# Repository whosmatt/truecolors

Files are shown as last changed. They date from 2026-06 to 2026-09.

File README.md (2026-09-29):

> [!CAUTION]
> This is not a manual! This repository serves as documentation only, use at your own risk.

# truecolors

This project captures a lot of embedded approaches I have picked up over the years and serves as my main ESP-IDF reference template for new projects that involve an embedded web UI w/ provisioning and OTA. 

Wide color gamut RGB Laser Mood Light  

I designed this light after growing fascinated with wide color gamut (110% BT.2020) rgb laser projectors. The colors are more vibrant and saturated than anything else. Even the best OLED screens look orange in comparison to the deep red produced by the almost monochromatic lasers.  
I got my hands on a Nichia NUMB12 Laser module, a very common module used in low to mid-tier RGB laser projectors.  
Unfortunately, the module is challenging to drive:
- Common cathode rules out most buck drivers which rely on a cathode shunt
- Forward voltage is very different between the green and red/blue channels
- Laser diodes are much more sensitive to overcurrent than LEDs
- The common cathode has a lower rating than the combined maximum currents, so staggered PWM is required to stay within the ratings

Beyond color gamut, this project also focuses on advanced audio reactive effects. Frustrated with RMS multiband effects, I trained a model to predict the presence and offset of beats in live audio, along with tagging drum hits.  
This allows effects to be completely locked into the tempo of a track rather than responding to volume changes. [truecolors-ml repo](https://github.com/whosmatt/truecolors-ml)

## Safety warning

The laser module used is a class 4 laser, with the output wavelength fully in the visible range. This means that the light has maximum eye damage potential and requires a robust safety protocol to be used safely. Use rated laser safety glasses and a shuttered room when testing without diffusers.

### Diffuser safety

I extensively tested the PLEXIGLAS® LED, Clear 0M200 SC diffuser material to ensure that it doesn't degrade under the intense laser light. Other diffuser materials **did** degrade and even slowly deform under the heat. High transmission is a must to minimize local heating, and the diffuser particles need to be the right size to ensure even diffusion across all three channels. Cheap diffusers may have a insufficient particle size, leading to a partially undiffused red beam passing straight through. Don't assume anything, test everything!

The diffuser design **must** include redundancy to ensure that the detachment/failure of a single diffuser does not compromise eye safety.

All fasteners relevant to eye safety must be secured with thread locker. Consider an additional hardware interlock.

## Hardware design

### PCB

A 4-Layer PCB was designed using Kicad 10. 4 layers were chosed to simplify USB 2.0 impedance and reduce laser driver EMI. Hierarchical design was used to keep the project organized, with Kicad's multichannel feature duplicating the laser driver layout. 

### MCU

An ESP32-S3 was chosen as the main controller for this project. It has plenty of power and the USB2.0 capability simplifies the design.  

ESP-IDF was used as the firmware framework, utilizing the rich scheduling and real-time capabilities of FreeRTOS.  
While most of my other projects rely on PlatformIO for toolchain management, I chose to use the official Espressif path for this to have more direct control over the build process.

### Power supply

USB C PD is used to power the design, with active negotiation to 20V/3A (bootstrapped by hardware and controlled by firmware).

### Laser driver

This design uses a customized constant off-time buck driver using the LM3409 switching converter IC. The design is common for all three channels and current is tuned by a multiturn potentiometer.  
COFT ensures known ripple amplitude, allowing the design to use minimal capacitance while staying safely within the laser's ratings.

Staggered PWM using the ESP32's MCPWM peripheral ensures that no two channels are on at the same time. An optional stretch parameters allows the channels to grow into the unused off time up to 100% combined duty with any color. This allows far higher brightness than with traditional staggered PWM.  
No gap was configured since the common cathode constraint is a thermal one, not an electrical one. 

### Temperature management

A heatpipe based server CPU cooler is used in conjunction with a Honeywell PTM7950 phase change thermal pad to keep the laser module cool.

A fine-adjustable 4-pin PWM server fan allows silent cooling with fine temperature control. This is important because the red laser diode array has a derating both above and below 45°C. The fan is PID controlled via the NTC thermistor located on the laser module.  
The tach signal is fed back to the MCU for fault monitoring. 

### Audio

A MSM261DGT003 PDM MEMS microphone is included for audio reactive effects. Connected to the ESP32's I2S peripheral in PDM mode.

A short recording was analyzed for coil whine cancellation: A single comb filter at the MCPWM frequency as well as a ~48db/oct 4kHz lowpass provided good results and leaves plenty of signal for audio reactive effects.

The first design was quite noisy, these mitigations have been tested and are already in the files:
- Lower noise inductors
  - C22396364 is footprint compatible and advertised as "ultra low buzz noise"
  - Small impact, because MLCC noise is dominant
- No output caps
  - With no output caps noise is reduced to a minimum
    Noise is still significantly audible at 240, 480 Hz. 120 Hz recommended
  - Requires carefully trimming to peak current via scope instead of average current
  - degraded EMI

The following hasn't been tested but is recommended:
- Low noise input caps
  - Murata ZRB: Drop in replacement with ~15dB reduction
  - Next board revision should allow for KRM series with ~25dB reduction

## Software design

### Audio

Core 1 is reserved for audio (including inference) and effect rendering.  

<details>
<summary>Audio pipeline diagram</summary>

```mermaid
flowchart TD
    MIC["PDM mic<br/>I2S RX, 48 kHz"] --> BLK["512-sample block<br/>93.75 blocks/s"]

    subgraph CORE1A["audio task: core 1, prio 5"]
        BLK --> FE["fe_block (frontend v2)<br/>DC block → 4 kHz hi-cut<br/>→ band split → multiband AGC"]
        BLK --> MEL["melflux_block<br/>1024 Hann (previous + current block)<br/>→ FFT → 16 mel bands 150 Hz - 4 kHz<br/>→ log10 → positive flux"]
        FE --> FEOUT["fe_out_t: 12 floats<br/>level, bands[3], rms, flux[3],<br/>fund_rms, mid_flux, treble_flux, spl_db"]
        FEOUT & MEL --> X["x: 28 floats"]

        X --> PA["stage A projection<br/>28 → 12, float"]
        PA --> RA["ring A: 272 blocks × 12"]
        RA --> WA["window: 528 floats<br/>16 fine + 16 mid + 12 coarse<br/>+2 block lookahead"]
        WA --> NNA[["TFLM + esp-nn, int8<br/>stage A 528→128→64 → beat<br/>76k MAC"]]
        NNA --> FB["stage A beat of the<br/>previous block: a[n-3]"]

        X & FB --> PB["stage B projection<br/>29 → 12, float"]
        PB --> RB["ring B: 272 blocks × 12"]
        RB --> WB["window: 528 floats"]
        WB --> NNB[["TFLM + esp-nn, int8<br/>stage B 528→64→32<br/>36k MAC"]]
        NNB --> HEADS["beat, beat_offset, hit[4], music"]

        HEADS -- beat --> TRACK["beattrack<br/>phase accumulator, latches each observation<br/>unlocked: fires on activation ≥ 0.5"]
        HEADS -- beat --> ABUF["tempo ringbuffer: 750 blocks / 8 s"]
        HEADS -- music --> GATE["musicgate<br/>median over ~2 s @ 0.7<br/>+ 3 s hold-off"]
    end

    subgraph CORE1B["estimator task: core 1, prio 3"]
        ABUF --> EST["tempo_estimate every 0.5 s, after ~14 s settle<br/>unbiased autocorr → harmonic sum, fractional lag →<br/>subharmonic → joint period+phase"]
        EST --> HOLD["hold: keep the held grid unless the candidate<br/>refines it, beats its contrast over the last 4 s<br/>by 0.02, or the held contrast drops below 0.03"]
    end

    HOLD -- "period, to_next, contrast<br/>(seqlock observation)" --> TRACK

    TRACK --> FEAT["audio_features_t<br/>level · bands[3] · beat · grid<br/>bpm · kicks · spl_db"]
    FEOUT --> FEAT
    GATE -. "currently debug only" .-> TEL

    FEAT --> FX["effects render task<br/>core 1, prio 18, 90 Hz<br/>reads beat, grid, bands"]
    FX --> LASER["laser_set → MCPWM"]

    HEADS -- *all* --> EVT["EVT_BEATGRID, block rate<br/>kick/snare/hihat/met<br/>act · music · off · err<br/>period · phase · bpm"]
    TRACK --> EVT
    FEAT --> TEL["metrics, 1 Hz<br/>audioDb · bpm<br/>nn.{beat,music,cycles,arena}<br/>nn.gate · nn.track · nn.selftest"]

    subgraph CORE0["core: 0"]
        EVT
        TEL
    end
```

</details> 

## Web UI

The Web UI is based on Svelte 5 and vite, and served as a gzipped static bundle. It is baked into the app partition via CMake's `target_add_binary_data`.  
A websocket endpoint is used to sync the UI state with the firmware, and events are propagated to other connected clients, making the UI multi-user capable.

## Development Environment & Build Instructions

The official Espressif dev container is used and should automatically be detected in VS Code. Build via the status bar, the command palette or just `idf.py build`.  
Build contains all stages, including web.  

### Tests

Critical components have unit tests via Unity, run them via `cd test/host && idf.py build && ./build/truecolors_host_tests.elf`.  

### Flashing & Debugging

Access to USB devices from the dev container is a little tricky. 
Refer to the [Espressif documentation](https://docs.espressif.com/projects/vscode-esp-idf-extension/en/latest/additionalfeatures/docker-container.html) for (partially out of date) instructions.  
WSL2 distros commonly don't have USB drivers loaded.  
Run `echo -e "cp210x\nch341\ncdc_acm" | sudo tee /etc/modules-load.d/esp.conf` inside your WSL2 distro and restart WSL2. The dev container is set up to get access to all ttyACM and ttyUSB class devices. Always make sure WSL2 is running before starting the dev container, as wsl is responsible for loading the kernel modules.  

Flashing via OTA: `curl -X POST --data-binary @build/truecolors.bin http://truecolors.local/api/ota`

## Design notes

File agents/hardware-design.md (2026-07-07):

# truecolors — Hardware Design Reference

Reference for firmware development. Describes the board, power tree, and every
ESP32 connection. Authoritative source is [`pcb/truecolors_driver.kicad_sch`](../pcb/truecolors_driver.kicad_sch);
this document reflects that schematic as built. See
[`timer-strategy.md`](timer-strategy.md) for the peripheral/timing plan.

## Project summary

110% BT.2020 mood light driven by a **Numb12 RGB laser array** (common cathode).
Each color is powered by its own **LM3409** P-channel buck LED driver (one
hierarchical sheet each: `driverR`, `driverG`, `driverB`, all instances of
`numb12_driver.kicad_sch`). The ESP32-S3 dims each color by PWM-ing the driver's
`EN`/PWM input.

**Hard constraint:** the laser array has a **common cathode and is NOT rated for
all diodes on simultaneously.** Firmware must guarantee the three colors are
driven **sequentially / non-overlapping** at all times — including during
brightness updates. This is enforced by the MCPWM scheme in
[`timer-strategy.md`](timer-strategy.md).

## MCU

**ESP32-S3-WROOM-1 (N8R8)** — 8 MB flash, 8 MB **octal** PSRAM.

- Octal PSRAM consumes **GPIO35, 36, 37** (datasheet Table 3-1 footnote b) — do
  not use. GPIO33/34 are not bonded out.
- Strapping pins (avoid for I/O that matters at boot): **GPIO0, 3, 45, 46**.
- Not 5 V tolerant — abs max ~3.6 V on any GPIO. Every pull-up that touches the
  ESP32 goes to **3.3 V**, never to 5 V or VBUS/20 V.
- Native USB-Serial-JTAG on GPIO19/20 is used for the USB port, so pad-JTAG
  (GPIO39/40 = MTCK/MTDO) is free for reuse as laser enables.

## Power tree

```
USB-C ──(PD sink: CH224A)──► +20V ──(AP63205 buck)──► +5V ──(AMS1117 LDO)──► +3.3V
         CFG1 = 120k → 20V        U1                    U4
```

| Rail  | Source | Notes |
|---|---|---|
| +20 V | USB-C VBUS, negotiated by **CH224A (U2)** PD sink | Feeds all three LM3409 laser drivers (VIN) and the +5 V buck |
| +5 V  | **AP63205WU-7 (U1)** buck, L4 = 4.7 µH | Fan supply + LDO input |
| +3.3 V| **AMS1117-3.3 (U4)** LDO | ESP32, pull-ups, sensor logic |

The 20 V rail establishes from the **CFG1 = 120 kΩ → GND** strap on the CH224A at
power-on, independent of firmware (single-resistor mode also auto-enables I²C on
CFG2/CFG3). Lasers are held off by their EN pulldowns until firmware drives them.

## Pin map (final, verified against schematic)

| Net | GPIO | Module pin | Peripheral (firmware) | Electrical notes |
|-----|---|---|---|---|
| EN_R | GPIO40 | 33 | MCPWM op (laser R) | active-high; 10k pulldown; → driverR PWM |
| EN_G | GPIO39 | 32 | MCPWM op (laser G) | active-high; 10k pulldown; → driverG PWM |
| EN_B | GPIO38 | 31 | MCPWM op (laser B) | active-high; 10k pulldown; → driverB PWM |
| VIN_ADC | GPIO4 | 4 | ADC1_CH3 | 20 V rail sense via divider (below) |
| FAN_PWM | GPIO6 | 6 | LEDC, 25 kHz | **inverted output** (low-side BSS138) |
| FAN_TACH | GPIO7 | 7 | PCNT | 10k (R25) pull-up to 3.3 V |
| CH224A_SDA | GPIO8 | 12 | I²C master SDA | 2.2k (R22) pull-up to 3.3 V |
| CH224A_SCL | GPIO9 | 17 | I²C master SCL | 2.2k (R23) pull-up to 3.3 V |
| IO0 / BOOT | GPIO0 | 27 | boot strap / button | SW1 + 10k (R16) pull-up to 3.3 V |
| TX / RX | GPIO43/44 | 37/36 | UART0 console | CN1 programming header |
| USB D-/D+ | GPIO19/20 | 13/14 | USB-Serial-JTAG | USB-C DM/DP |
| MIC_CLK | GPIO12 | 20 | I²S PDM CLK | no series R (short trace); → MIC1 CLK |
| MIC_DATA | GPIO13 | 21 | I²S PDM DATA RX | no series R (short trace); ← MIC1 DATA |
| NTC_ADC | GPIO10 | 18 | ADC1_CH9 | laser module NTC sense via divider (below) |
| LED_DATA | GPIO11 | 19 | RMT TX | WS2812B-B data |

## Subsystems

### Laser drivers (R / G / B) — LM3409

- Each color = one LM3409MY P-channel buck on its own sheet, `VIN = +20 V`,
  output to the laser, common cathode to GND.
- The `EN`/PWM input is **directly 3.3 V compatible and active-high** (high =
  laser current on). Driven by MCPWM — see [`timer-strategy.md`](timer-strategy.md).
- **Boot safety:** each EN net has a **10 kΩ pulldown** so the laser is OFF while
  the GPIO is Hi-Z (reset / flashing / before firmware init).
- The LM3409 dims by gating EN; each rising edge restarts the converter, which
  needs settle time. This sets a **dimming floor** (shortest useful on-time ≈
  converter settle time, `MIN_ON_US` = 8 µs) and argues for a **low** PWM/cycle
  frequency — see the timing doc for the rationale.
- **Low-power shutdown (measured, datasheet §8.4.1):** a sustained EN low lets
  the VCC bias rail (regulated ~6.2 V below VIN, held by a 1 µF cap) decay past
  UVLO into 110 µA shutdown; the next enable pays a soft restart visible as a
  fade-in. Short PWM-dimming lows keep the support circuitry alive (§8.3.6);
  tens-of-ms dark states do not. EN is a single Schmitt input (rising ≤1.74 V,
  falling ≥0.5 V) — there is **no intermediate "standby" drive level**, so the
  fix is temporal: firmware floors dark channels at MIN_ON pulses for effects
  that strobe from black (`keepalive` flag).

### Fan — 4-wire (5-pin) PC fan, run on 5 V via low-side PWM

Connector **CN2 = Molex 47053-1000** fan header. The fan is a 12 V 4-wire PC fan
run on **+5 V** (validated: smooth control).

- **CN2 pin 1** = GND, **pin 2** = +5 V, **pin 3** = TACH, **pin 4** = PWM control.
- The fan's PWM input does **not** meet Intel logic levels — measured idle ≈
  **1.58 V** on 5 V supply (≈3.3 V on 12 V).
- **Measured transfer (2026-07-07): the fan never fully stops.** Holding the
  PWM line at GND leaves a ~84 rpm min-speed floor (vendor behavior); response
  is dead until a **19% duty knee**, then linear `rpm ≈ 1875·duty − 250` to
  1621 rpm at 100%, no hysteresis. Firmware remaps the PID output onto
  `[knee, 1]` accordingly.
- **Control = low-side switch via BSS138 (Q4):**
  - Gate ← FAN_PWM (GPIO6), with **R26 pull-up to 3.3 V** (boot disabled).
  - Source → GND.
  - Drain → CN2 pin 4.
  - The fan's own internal pull-up provides the idle-HIGH (no external pull-up).
- **Inverted logic:** GPIO6 HIGH → FET on → fan PWM line LOW → fan OFF.
  Firmware sets `output_invert` so the LEDC duty register maps directly to fan
  speed (see timing doc).
- **Boot behavior:** while GPIO6 is Hi-Z, R26 pulls the gate HIGH → FET on →
  fan PWM line held LOW → **fan disabled at boot** until firmware takes over.
- **TACH (CN2 pin 3):** open-collector, 2 pulses/rev (confirmed), pulled up to
  3.3 V (R25 10k). Valid because the fan supply is constant 5 V (not chopped).
  Read with PCNT, both edges over a 1 s window (15 rpm resolution).
- The fan's 5th pin (presence-detect to GND) is **not used**.

### 20 V rail measurement — ADC

- Divider: **R21 = 68 kΩ (top, from +20 V)** / **R20 = 10 kΩ (bottom)**, with
  **C40 = 100 nF** across the bottom for filtering + ADC sample charge reservoir.
- Scale factor: `V_rail = V_adc × (68 + 10) / 10 = V_adc × 7.8`.
  20 V → 2.56 V at the ADC; clips near ~24 V (≈21% headroom).
- Read on **ADC1_CH3 (GPIO4)** — ADC1 only, since ADC2 is unusable while Wi-Fi is
  active. Use 12 dB attenuation, eFuse calibration, oversample.
- This is the only **measured** rail voltage; the CH224A reports negotiated gear
  and current capability but not actual VBUS, so this divider is not redundant.

### Microphone — MSM261DGT003 PDM MEMS (MIC1)

- **MSM261DGT003**: omnidirectional, top-ported, 4×2×1.1 mm LGA, VDD = 3.3 V
  (1.6–3.6 V range; 670 µA typical in standard mode).
- **MIC_CLK (GPIO12)** → CLK; **MIC_DATA (GPIO13)** ← DATA. No series resistors
  (traces < 5 mm; ESD diodes also omitted for this enclosed prototype).
- **L/R (pin 6) = GND** → left-channel / Mic(Low): mic asserts DATA on CLK falling
  edge, host latches on rising edge. Matches ESP-IDF I²S PDM-RX default.
- **VDD decoupling**: 100 nF + 10 µF ceramic (C41, C42) immediately at pin 1.
- **Clock**: standard performance mode requires 1.1–4.0 MHz. Use ~3.072 MHz
  (48 kHz × 64); drive from ESP32-S3 I²S peripheral in PDM-RX mode.
- Mode is set by clock frequency alone — sleep ≤ 50 kHz, low-power 150–900 kHz,
  standard 1.1–4.0 MHz. No control register.
- **Top-ported package**: acoustic port faces away from PCB

### Status LED — WS2812B-B (LED1)

- Single WS2812B-B RGB LED; VDD = **+5 V** (from the +5 V rail), GND.
- **LED_DATA (GPIO11, module pin 19)** → data in. Driven by **RMT TX** peripheral
  (one of 4 available channels; none previously allocated).
- Firmware: ESP-IDF `led_strip` driver (RMT backend). For static color, write once
  at init; LED holds state until power-cycled. Reset pulse ≥ 50 µs handled
  automatically by the driver.

### Laser module NTC — temperature monitoring

- **10 kΩ NTC, B = 3950**, mounted on the Numb12 laser module (nominal operating
  temperature 45 °C).
- Read on **ADC1_CH9 (GPIO10, module pin 18)** — ADC1 only (ADC2 unusable with
  Wi-Fi active). GPIO10 is the last free ADC1 pin; sits adjacent to MIC_CLK/DATA.
- **Divider**: 10 kΩ pullup to 3.3 V (near ESP32) / NTC lower leg to GND.
  Midpoint ≈ 1.0 V at 45 °C, well within 12 dB attenuation range.
- **Filter cap**: 100 nF across NTC at the board-edge connector (NTC cable entry),
  not at the ESP32. Filters cable-induced noise at the source. No second cap at the
  ESP32 end — without series impedance between them the two caps would simply be in
  parallel, losing the entry-point filtering benefit.
- Measurement range: −14 °C to +114 °C; resolution ~0.03 °C/LSB at 45 °C.
- ADC config: same as VIN_ADC — 12 dB attenuation, eFuse calibration, oversample.
- Temperature conversion (B-value equation):
  ```c
  float r_ntc  = 10000.0f * v_adc / (3.3f - v_adc);
  float temp_k = 3950.0f / (logf(r_ntc / 10000.0f) + 3950.0f / 298.15f);
  float temp_c = temp_k - 273.15f;
  ```
- **Safety interlock**: add NTC in-range check to the laser-enable gate alongside
  PD handshake and VIN ADC checks (see safety invariant 2).

### USB-C PD sink — CH224A (I²C-only)

- Negotiates **20 V** from the USB-C source. CFG1 = 120 kΩ → GND selects 20 V and
  enables I²C; PG pin is **not connected** (monitoring is via I²C polling only).
- I²C: 400 kHz, **7-bit address 0x22 or 0x23** (confirm on hardware), **single-
  byte read/write only** (no auto-increment).
- Registers used by firmware:
  - **0x09** (RO, status): bit3 = PD handshake good; bits 0/1/2 = BC/QC2/QC3;
    bit5 = EPR exist; bit6 = AVS exist.
  - **0x50** (RO, current): max available current in the negotiated gear, unit
    **50 mA/count** (valid only after handshake).
  - **0x0A** (WO, voltage): request gear — `0`=5 V, `1`=9 V, `2`=12 V, `3`=15 V,
    `4`=20 V, `5`=28 V. Not required (CFG1 strap already selects 20 V), but
    available to re-assert/override.
- **No hardware fault interlock** (PG dropped): firmware must gate laser enable on
  I²C checks (PD good + adequate current) and the ADC reading, and re-poll
  periodically.

## Safety invariants for firmware

1. **Never drive two laser EN lines high at once** (common cathode) — guaranteed
   by the MCPWM single-timer scheme with Σ(on-time) + guards ≤ period and atomic
   updates. See [`timer-strategy.md`](timer-strategy.md).
2. **Lasers off until power is confirmed:** before enabling MCPWM laser outputs,
   confirm CH224A PD handshake (0x09 bit3) + sufficient current (0x50) + ADC rail
   in range + NTC temperature in range. The 10k EN pulldowns hold lasers off until
   then; re-check NTC periodically and disable on over-temperature.
3. **All ESP32-facing pull-ups go to 3.3 V**, never 5 V/20 V (not 5 V tolerant).
4. Supply current budget: compare the CH224A-reported budget (0x50 × 50 mA)
   against the measured draw model `I(V) ≈ 3.68 − 0.106·V` + 0.2 A margin
   (2.4 A @ 12 V, 2.1 A @ 15 V, 1.55 A @ 20 V). A short budget raises the
   undercurrent **warning only** — no brightness limiting; an actual overdraw
   trips the PD supply, and the light recovers to its default-off boot state.

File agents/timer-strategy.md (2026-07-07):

# truecolors — Timer / Peripheral Strategy

Firmware reference for how the ESP32-S3 hardware peripherals generate all timed
signals. Goal: do everything in hardware, no software-bit-banged PWM. Pin/net
details are in [`hardware-design.md`](hardware-design.md).

Peripheral allocation:

| Subsystem | Peripheral | Why |
|---|---|-----|
| RGB lasers | **MCPWM** (1 group, 1 timer, 3 operators) | phase-shifted non-overlapping pulses + atomic synchronous update |
| Fan speed | **LEDC** (1 timer + 1 channel, 25 kHz) | simple high-res PWM, inverted output |
| Fan tach | **PCNT** | hardware pulse counting, zero CPU |
| Rail voltage | **ADC1** (CH3) + calibration | ADC2 unusable with Wi-Fi |
| PD sink status | **I²C master** (polled) | CH224A status/current registers |

---

## 1. Laser PWM — the core scheme

### Concept: phase-shifted PWM with Σduty ≤ 100%

The requirements — *sequential / non-overlapping*, *common cathode never all-on*,
*stretchable slots (R can be 100% if G=B=0)*, *brightness = on-time* — are all one
waveform: **three phase-offset pulses sharing one timer period**, where the sum of
the three pulse widths (plus guard gaps) is ≤ the period.

- Non-overlap ⇒ common-cathode-safe, for free.
- "Stretch" ⇒ free: any single color can take (almost) the whole period when the
  others are 0; the only rule is Σ ≤ period.
- Brightness of a color = its pulse width / period.

### MCPWM mapping

One MCPWM **timer** sets the period; three **operators** share it, each producing
one pulse via its two comparators (set output HIGH at CMPA, LOW at CMPB):

```
period T  ├─────────────────────────────────────────────┤  (repeats)
R         ███████░                                            high 0 → dR
G                 ░░gap░░███████░                             high dR+gap → dR+gap+dG
B                              ░░gap░░██████░                 high ... → ...+dB
                                            ░░gap░░  (wrap)
```

- R: CMPA = 0,                           CMPB = dR
- G: CMPA = dR + gap,                     CMPB = dR + gap + dG
- B: CMPA = dR + 2·gap + dG,              CMPB = dR + 2·gap + dG + dB
- **Invariant:** `dR + dG + dB + 3·gap ≤ T` (three guard gaps: R→G, G→B, B→wrap).

Outputs are **active-high, NOT inverted** (LM3409 EN: high = laser on).

### Frequency choice

- One timer period = one full R→G→B sequence, so **PWM frequency = RGB cycle
  frequency** (the two collapse into a single waveform — do NOT stack a second
  higher-frequency PWM on top; for a buck driver that only adds settling losses).
- **Runtime-adjustable: 120 / 240 / 480 Hz** (settings dropdown → WS
  `set_pwm_hz` → NVS `pwm_hz`), default **120 Hz** — quietest coil whine, still
  above flicker fusion for a static light. Lower frequency = better buck
  behavior, more dimming range, quieter; higher = more motion robustness.
- Frequency changes are glitch-free while running: the period and all six
  comparators shadow-load on the same TEZ (`update_period_on_empty`), and
  `laser_set_pwm_hz()` orders the writes so a TEZ landing mid-update never
  leaves a compare beyond the counter range (growing period → period first,
  shrinking → comparators first).

### Resolution

The MCPWM group clock runs at **5 MHz** (0.2 µs/tick): the period register is
**16-bit** (max 65,535 ticks), and 120 Hz needs 41,666 — a 10 MHz clock cannot
reach below ~153 Hz. At 480 Hz the period is still 10,416 ticks (~13 bits),
far more brightness resolution than needed.

### Wrap-tick reservation (learned the hard way)

The up-counter counts `[0, period−1]`; a compare value equal to the period tick
is accepted by the driver but **never fires** — the clear action is lost and the
channel latches ON at 100% duty, overlapping its neighbors (observed as bright
flashes at crossfade corners with stretch > 25%). The width math therefore
reserves the last tick so every clear compare stays reachable; a width of
period−1 means "fully on" and laser.c drives it as a DC force level instead of
chopping a one-tick notch into EN.

### Guard interval (`gap`)

Settled at **0**. The common-cathode constraint is thermal, not electrical —
these are three independent bucks, not an H-bridge, so there is no
shoot-through path and back-to-back pulses are fine. The gap stays plumbed
through `laser_math.c` should it ever be needed.

### Atomic, glitch-free updates (critical)

Brightness changes must never momentarily push two pulses into overlap. With
MCPWM, **stage all three operators' new CMPA/CMPB and load them synchronously on
the timer zero event (TEZ)** so the three pulses always move as one set and the
`Σ + guards ≤ T` invariant holds every period. Use the MCPWM compare-update-on-
TEZ mechanism; do not update operators one at a time without sync.

### Brightness → on-time pipeline (firmware)

1. Inputs: desired per-color brightness `bR, bG, bB` (0…1, e.g. after gamma).
2. Compute raw widths: `dX = bX × T_available`, where
   `T_available = T − 3·gap`.
3. **Normalize if over budget:** if `dR + dG + dB > T_available`, scale all three
   by `T_available / (dR+dG+dB)` (preserves color ratio) — or clip per policy.
   When the sum is under budget, no scaling: unused time is just idle (all lasers
   off), which is correct.
4. Compute the three (CMPA, CMPB) pairs as above.
5. Stage + sync-load on TEZ.

> Note: normalization couples absolute brightness to the sum. If you want
> "stretch for max brightness" behavior (one color brighter when others are dim),
> that is exactly step 3 with scaling only on overflow — a dim scene leaves the
> bright color at its requested width, a maxed-out white scene shares the period.

### Width floors and the LM3409 keepalive

- A nonzero width below **MIN_ON** (8 µs LM3409 settle floor) snaps up to it.
- **LM3409 low-power shutdown (measured):** a sustained EN low lets the IC's
  VCC bias cap decay below UVLO into 110 µA shutdown; the next enable pays a
  soft restart that shows as a visible fade-in. Normal PWM-dimming lows (≤ one
  period) never trigger it, but tens-of-ms dark states do. Effects that strobe
  from black (discombobulate, audio) set a `keepalive` flag: commanded-dark
  channels then idle at MIN_ON pulses to keep the bias awake. The power switch,
  safety latch, boot gate and brightness-zero still drop to true black.

### Optional power/thermal cap

Σduty ≤ 100% already guarantees at most one laser on at a time (cathode safe). A
separate firmware policy may further cap the **sum of brightnesses** to stay
within the CH224A current budget (0x50) and array thermal limits.

---

## 2. Fan PWM — LEDC, inverted

- **LEDC**, one timer + one channel, **25 kHz** (inaudible; 40 µs period rides
  through the fan's internal commutation so no stutter), on **GPIO6**.
- Hardware is a **low-side BSS138** (gate-driven): GPIO HIGH → FET on → fan PWM
  line LOW → fan OFF. So **set `ledc_channel_config_t.flags.output_invert = 1`**.
  With invert, the **LEDC duty register maps directly to fan speed**.
- **Measured transfer curve (2026-07-07):** the fan never fully stops — ~84 rpm
  floor at 0% duty (vendor min-speed behavior; PWM line verified held low),
  dead until a **19% knee**, then linear `rpm ≈ 1875·duty − 250` up to 1621 rpm
  at 100%, no hysteresis. The PID output is treated as *cooling demand* and
  remapped onto `[FAN_KNEE_DUTY, 1]` so the loop sees a linear plant
  (see `fancontrol.c`).
- Resolution: a few hundred steps is plenty; e.g. 10-bit at 25 kHz.
- **Boot behavior:** before LEDC init, GPIO6 is Hi-Z, R26 pulls the gate HIGH →
  FET on → fan line held LOW → **fan disabled at boot**. Initialize LEDC at any
  point in startup; fan stays off until commanded.

## 3. Fan tach — PCNT

- **PCNT** unit counting edges on **GPIO7** (FAN_TACH, pulled to 3.3 V).
- `pulses_per_rev = 2` (confirmed on hardware). Count **both edges**
  (4 edges/rev) and integrate a full **1 s window** before computing: at a
  100 ms poll a single pulse is worth 300 rpm of quantization, while the
  both-edge 1 s window resolves 15 rpm — needed to see the ~84 rpm idle floor.
- Valid because the fan supply is constant 5 V (not chopped) — tach references a
  stable ground.

## 4. Rail voltage — ADC1

- **ADC1_CH3 / GPIO4**, 12 dB attenuation, eFuse calibration (`adc_cali`).
- `V_rail = V_adc × 7.8` (68k/10k divider; C40 = 100 nF filter).
- Oversample (e.g. average N samples). ADC1 mandatory — ADC2 is blocked while
  Wi-Fi is on. Use as a sanity check on the actual 20 V rail (sag detection),
  complementary to the CH224A's negotiated-gear info.

## 5. PD sink (CH224A) — I²C polling

- **I²C master**, SDA = GPIO8, SCL = GPIO9, 400 kHz, address **0x22/0x23**
  (confirm), **single-byte transactions only**.
- Startup gate sequence before enabling lasers:
  1. (20 V already requested by the CFG1 strap.)
  2. Poll **0x09** until bit3 (PD) = 1 → handshake good.
  3. Read **0x50** → max current = value × 50 mA; compare against the measured
     draw model `I(V) = 3.68 − 0.106·V` + 0.2 A margin (2.4 A @ 12 V …
     1.55 A @ 20 V). A short budget is a **warning only** — no brightness
     limiting; an actual overdraw trips the supply, and the light recovers to
     its default-off boot state.
  4. Confirm ADC rail in range.
  5. Then start MCPWM laser outputs.
- Re-poll 0x09 / 0x50 periodically at runtime. There is **no hardware PG
  interlock** — this poll + the ADC are the only power-fault detection, so on a
  failed check, command all laser widths to 0 (and rely on the EN pulldowns).

---

## Init order (suggested)

1. GPIO defaults / ensure EN pulldowns effective (lasers off).
2. LEDC fan (optional: set a sane speed early to quiet the full-speed boot state).
3. I²C + CH224A startup gate (PD good, current budget, ADC rail check).
4. MCPWM timer + 3 operators, TEZ-synced compare updates, start with all widths 0.
5. Begin the brightness control loop (gamma → widths → normalize → sync-load).

## Resolved on hardware

- CH224A I²C address: firmware probes 0x22 then 0x23 at init.
- Fan `pulses_per_rev` = 2, confirmed; full transfer curve measured (see §2).
- Guard `gap` = 0 — thermal constraint, not electrical.
- Laser cycle frequency: runtime dropdown 120/240/480 Hz, default 120 Hz
  (coil whine); MCPWM group clock 5 MHz to fit 120 Hz in the 16-bit period.
- LM3409 low-power shutdown on sustained EN low → `keepalive` width floor.

## Open items to confirm on hardware

- MIN_ON_US (LM3409 settle floor) — 8 µs assumed, verify on scope.

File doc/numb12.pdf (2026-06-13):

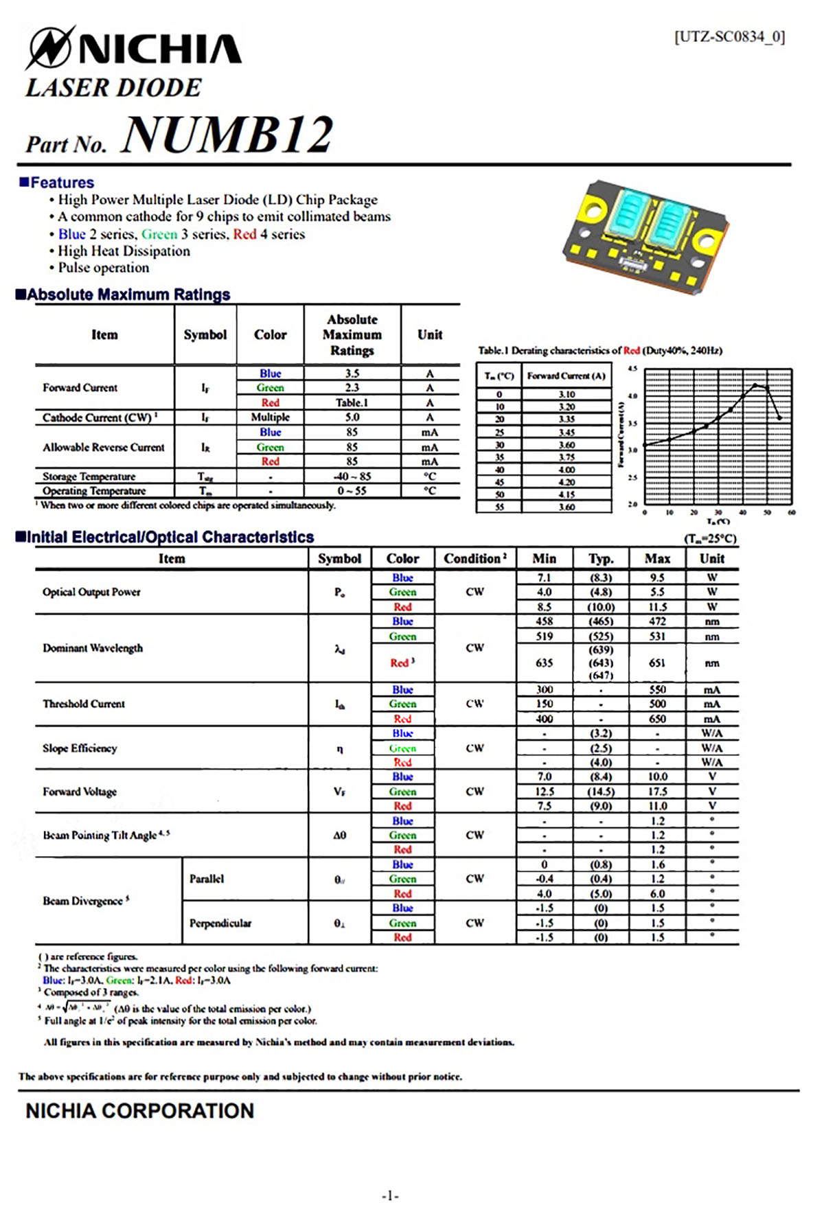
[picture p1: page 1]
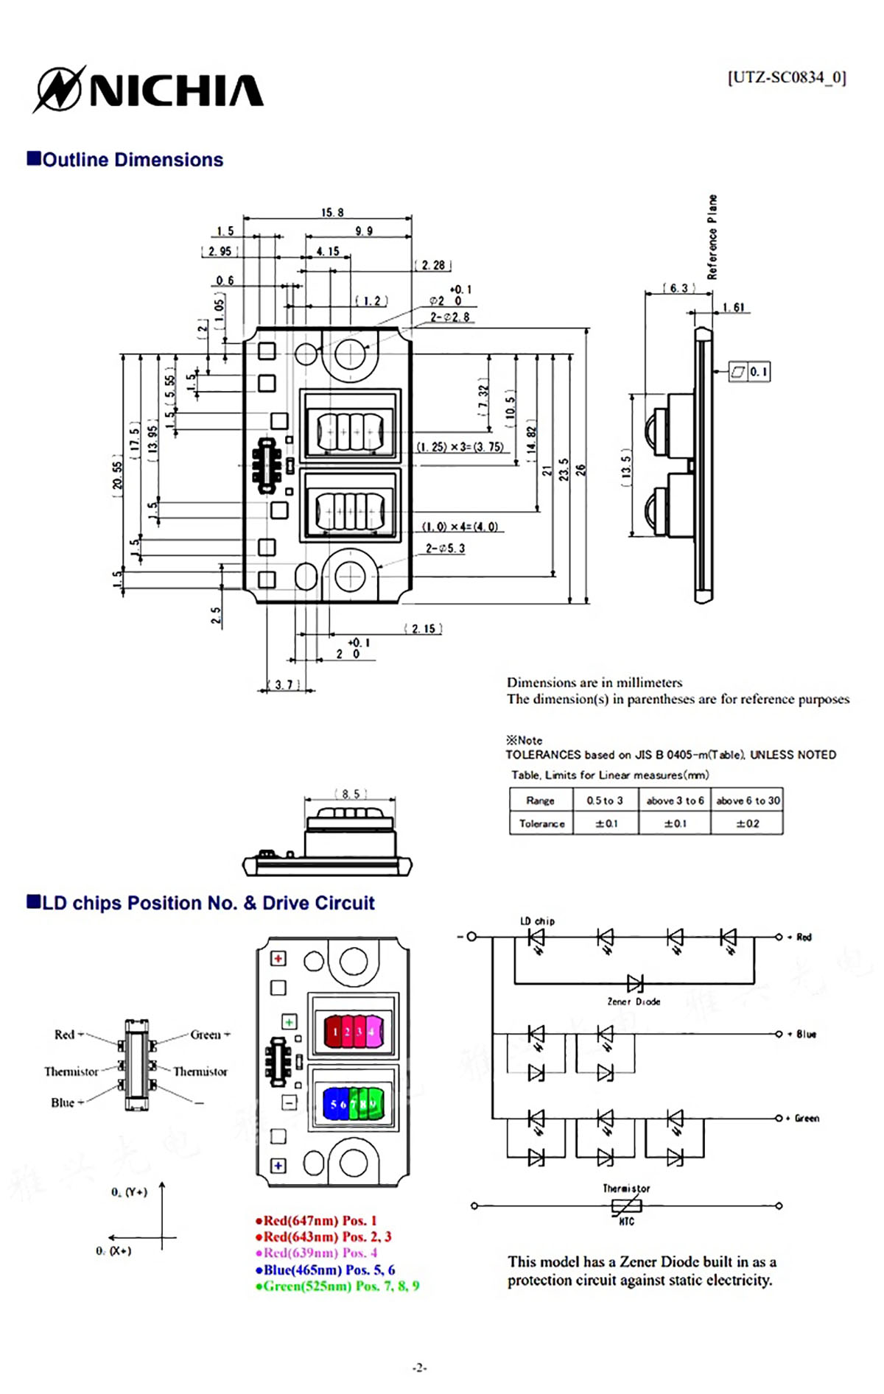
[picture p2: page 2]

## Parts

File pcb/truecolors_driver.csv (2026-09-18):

Reference | Value | Datasheet | Footprint | Qty | DNP | Exclude from BOM | LCSC Part
C1,C7,C17,C27 | 1uF 50V |  | Capacitor_SMD:C_0603_1608Metric | 4 |  |  | C5199872
C2,C3,C34,C36,C37,C38,C39,C42 | 10uF 25V |  | Capacitor_SMD:C_0603_1608Metric | 8 |  |  | C96446
C4,C5,C6,C13,C14,C15,C16,C23,C24,C25,C26,C33 | 4.7uF 35V |  | Capacitor_SMD:C_0603_1608Metric | 12 |  |  | C307467
C8,C18,C28 | 470pF 50V |  | Capacitor_SMD:C_0603_1608Metric | 3 |  |  | C16194503
C9,C10,C11,C12,C19,C20,C21,C22,C29,C30,C31,C32 | 4.7uF 35V |  | Capacitor_SMD:C_0603_1608Metric | 12 | DNP |  | C307467
C35,C40,C41,C43 | 100nF 16V |  | Capacitor_SMD:C_0603_1608Metric | 4 |  |  | C346192
CN1 | 1.0-3PWT | https://www.lcsc.com/datasheet/C2763613.pdf | EasyEDA:CONN-SMD_3P-P1.00_C3029342 | 1 |  |  | C2763613
CN2 | 47053-1000 | https://lcsc.com/product-detail/Others_MOLEX_47053-1000_MOLEX-47053-1000_C240840.html | EasyEDA:CONN-TH_47053-1000 | 1 |  |  | C240840
D1,D2,D3 | SBR8U60P5-13 | https://lcsc.com/product-detail/Diodes-General-Purpose_DIODES_SBR8U60P5-13_SBR8U60P5-13_C154726.html | Library:POWERDI-5_L5.4-W4.0-LS6.5-RD-thermal | 3 |  |  | C154726
L1,L2,L3 | SMPQ1306-220MT |  | easyeda2kicad:IND-SMD_L13.5-W12.8_APH1265T | 3 |  |  | C22396364
L4 | 4.7uH | https://www.lcsc.com/datasheet/C5349668.pdf | EasyEDA:IND-SMD_L4.4-W4.2 | 1 |  |  | C5349668
LED1 | WS2812B-B | https://lcsc.com/product-detail/Light-Emitting-Diodes-LED_5050-RGBIntegrated-Light-4Pin_C114586.html | EasyEDA:LED-SMD_4P-L5.0-W5.0-BL_TC5050RGB | 1 |  |  | C114586
MIC1 | MSM261DGT003 | https://www.lcsc.com/datasheet/C48227730.pdf | EasyEDA:MIC-SMD_6P-L4.0-W2.0_LMD4020T261-OC3 | 1 |  |  | C48227730
Q1,Q2,Q3 | AOD413A(UMW) |  | Library:TO-252-3_L6.6-W6.1-P4.57-LS9.9-BR-CW-thermal | 3 |  |  | C19100585
Q4 | BSS138 | https://www.onsemi.com/pub/Collateral/BSS138-D.PDF | Package_TO_SOT_SMD:SOT-23 | 1 |  |  | C52895
R1,R6,R11 | 50k |  | Resistor_SMD:R_0603_1608Metric | 3 |  |  | C861451
R2,R7,R12 | 6k8 |  | Resistor_SMD:R_0603_1608Metric | 3 |  |  | C2907055
R3,R8,R13 | 3296W-1-254LF | https://lcsc.com/product-detail/Precision-Potentiometer_BOURNS_3296W-1-254LF_250KR_C83691.html | Library:RES-ADJ-TH_3296W-clean | 3 |  |  | C83691
R4,R9,R14 | 14k |  | Resistor_SMD:R_0603_1608Metric | 3 |  |  | C723488
R5,R10,R15 | 75m 675mW |  | Resistor_SMD:R_1206_3216Metric | 3 |  |  | C2904225
R16,R17,R18,R19,R20,R25,R27 | 10k |  | Resistor_SMD:R_0603_1608Metric | 7 |  |  | C2906982
R21 | 68k |  | Resistor_SMD:R_0603_1608Metric | 1 |  |  | C114633
R22,R23 | 2k2 |  | Resistor_SMD:R_0603_1608Metric | 2 |  |  | C2907005
R24,R26 | 120k |  | Resistor_SMD:R_0603_1608Metric | 2 |  |  | C2907095
SW1 | TS-1088-AR02016 | https://lcsc.com/product-detail/Tactile-Switches_XUNPU-TS-1088-AR02016_C720477.html | EasyEDA:SW-SMD_L3.9-W3.0-P4.45 | 1 |  |  | C720477
U1 | AP63205WU-7 | https://www.lcsc.com/datasheet/C2071056.pdf | EasyEDA:TSOT-23-6_L2.9-W1.6-P0.95-LS2.8-BL | 1 |  |  | C2071056
U2 | CH224A |  | easyeda2kicad:ESSOP-10_L4.9-W3.9-P1.0-LS6.0-TL-EP | 1 |  |  | C42459160
U3 | ESP32-S3-WROOM-1(N8R8) |  | easyeda2kicad:WIRELM-SMD_ESP32-S3-WROOM-1 | 1 |  |  | C2913201
U4 | AMS1117-3.3 | https://lcsc.com/product-detail/Low-Dropout-Regulators-LDO_AMS_AMS1117-3-3_AMS1117-3-3_C6186.html | easyeda2kicad:SOT-223-3_L6.5-W3.4-P2.30-LS7.0-BR | 1 |  |  | C6186
U5,U6,U7 | LM3409MY/NOPB |  | Library:HVSSOP-10_L3.0-W3.0-P0.50-LS4.9-BL-EP-thermal | 3 |  |  | C527401
USBC1 | TYPE-C-31-M-12 | https://lcsc.com/product-detail/USB-Type-C_Korean-Hroparts-Elec-TYPE-C-31-M-12_C165948.html | easyeda2kicad:USB-C_SMD-TYPE-C-31-M-12_1 | 1 |  |  | C165948

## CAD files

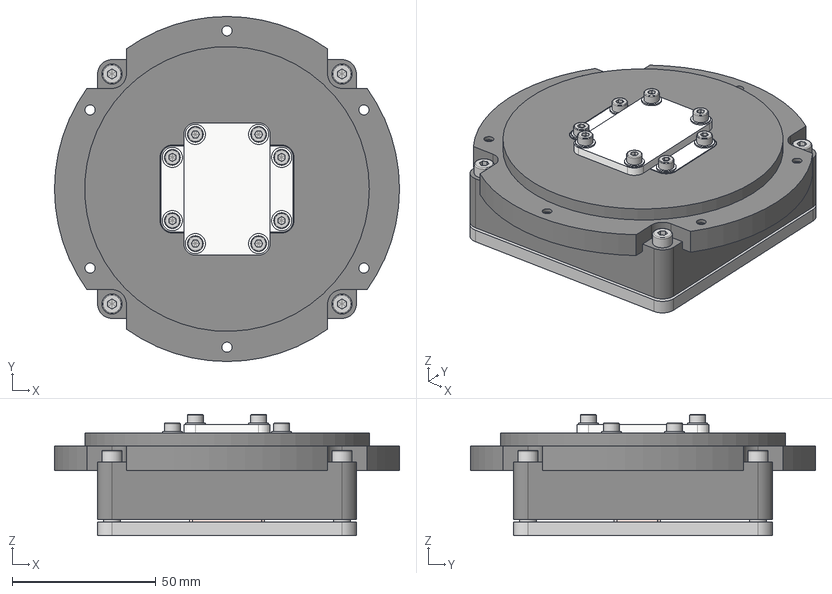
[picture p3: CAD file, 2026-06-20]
mechanical/full assy.step
120.0 x 120.0 x 42.2 mm
NUMB12
Heatsink
Diffusor x 2
DIN 912 - M3 x 0.5 x 8 Steel 4.6 Plain x 8
DIN 433 - 3.7 Steel 100 HV Plain x 8
DIN 912 - M4 x 0.7 x 8 Steel 4.6 Plain x 4

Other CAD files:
mechanical/full assy.f3z

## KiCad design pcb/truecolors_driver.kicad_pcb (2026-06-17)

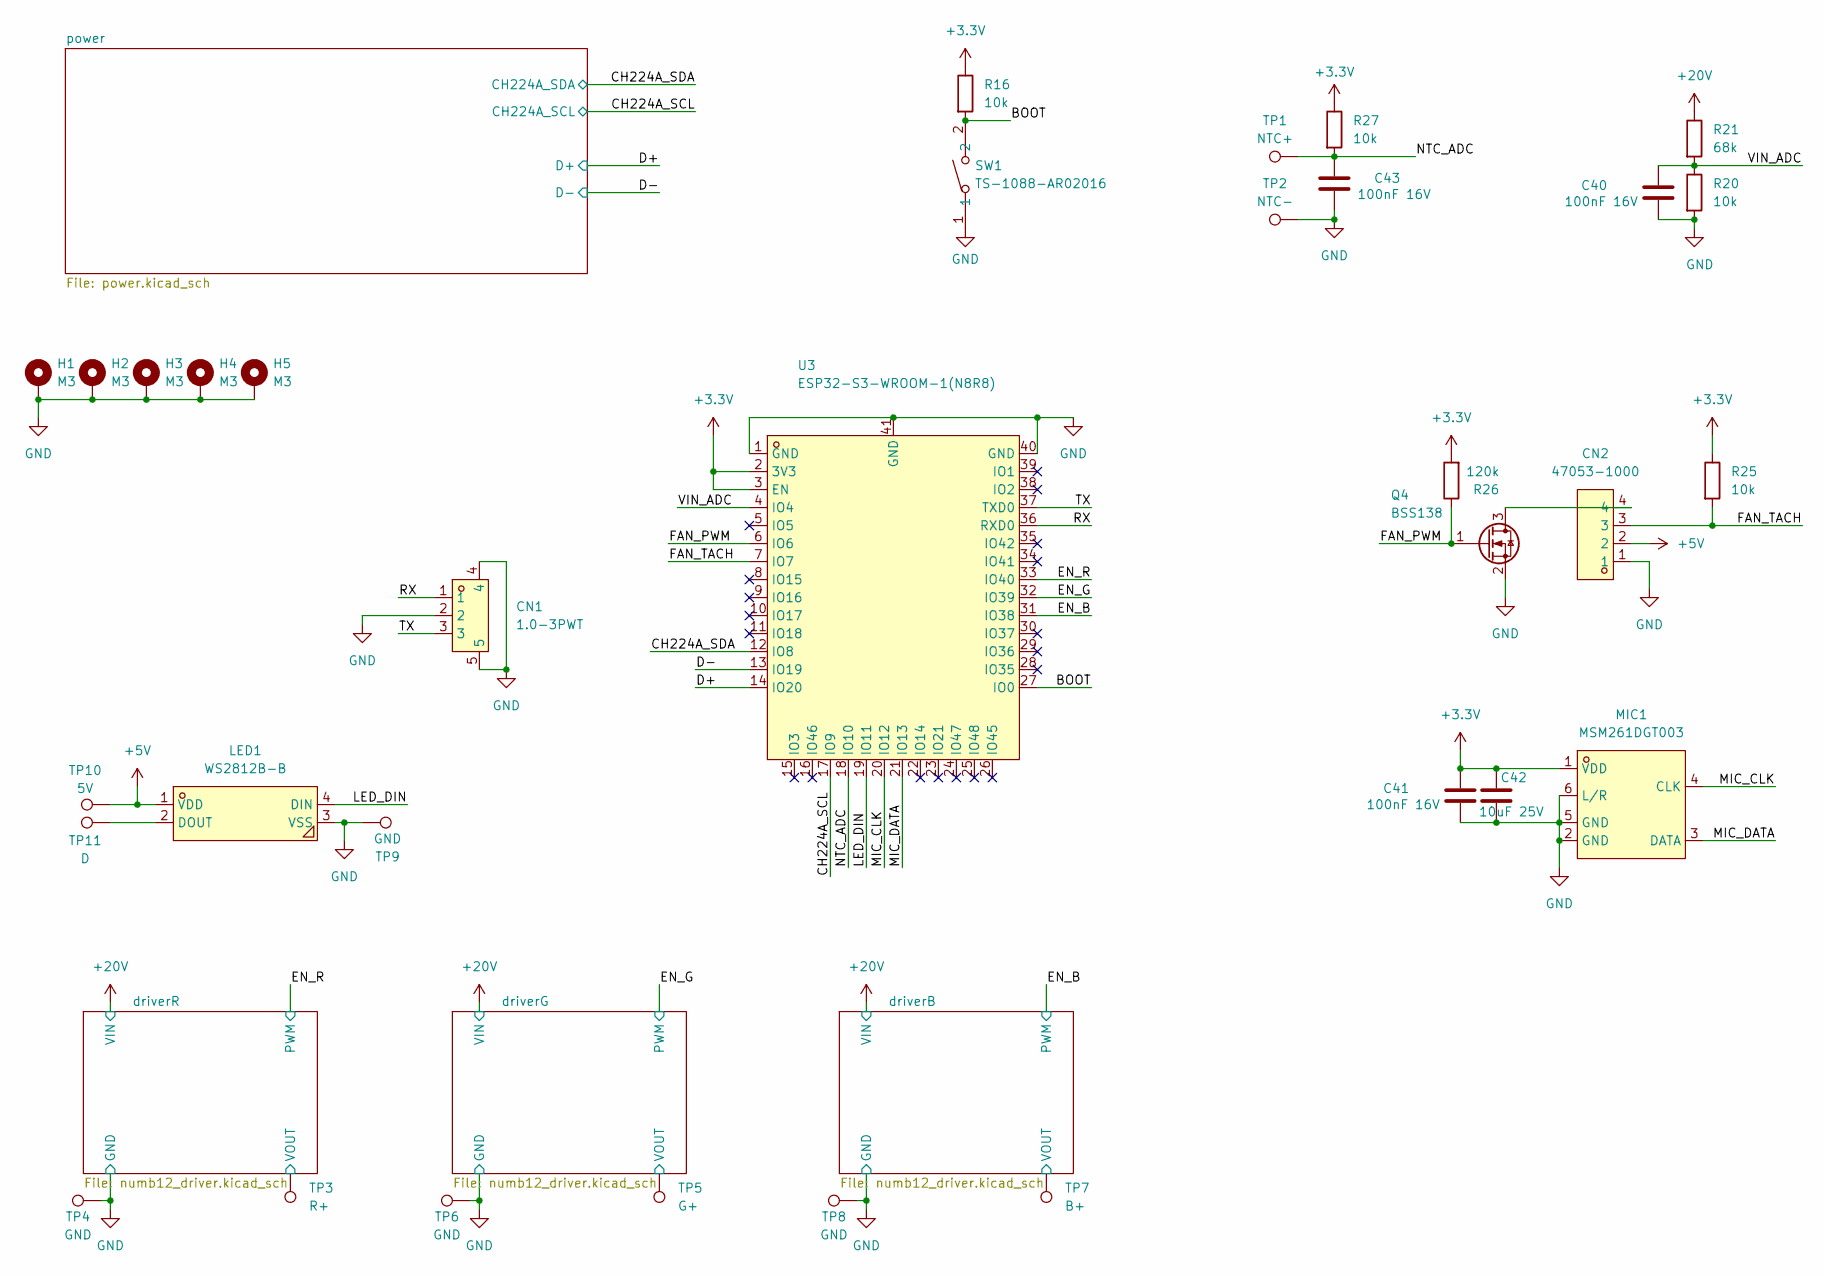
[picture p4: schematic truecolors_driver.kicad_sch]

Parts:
C40, C41, C43: 100nF 16V; C_0603_1608Metric; LCSC Part C346192
C42: 10uF 25V; C_0603_1608Metric; LCSC Part C96446
CN1: 1.0-3PWT; CONN-SMD_3P-P1.00_C3029342; MPN 1.0-3PWT; LCSC Part C2763613
CN2: 47053-1000; CONN-TH_47053-1000; MPN 470531000; LCSC Part C240840
H1, H2, H3, H4, H5: M3; MountingHole_3.2mm_M3_DIN965_Pad
LED1: WS2812B-B; LED-SMD_4P-L5.0-W5.0-BL_TC5050RGB; MPN WS2812B-B/W; LCSC Part C114586
MIC1: MSM261DGT003; MIC-SMD_6P-L4.0-W2.0_LMD4020T261-OC3; MPN MSM261DGT003; LCSC Part C48227730
Q4: BSS138; SOT-23; LCSC Part C52895
R16, R20, R25, R27: 10k; R_0603_1608Metric; LCSC Part C2906982
R21: 68k; R_0603_1608Metric; LCSC Part C114633
R26: 120k; R_0603_1608Metric; LCSC Part C2907095
SW1: TS-1088-AR02016; SW-SMD_L3.9-W3.0-P4.45; MPN TS-1088-AR02016; LCSC Part C720477
TP1: NTC+; TestPoint_Keystone_5019_Miniature
TP2: NTC-; TestPoint_Keystone_5019_Miniature
TP3: R+; TestPoint_Keystone_5019_Miniature
TP4, TP6, TP8: GND; TestPoint_Keystone_5019_Miniature
TP5: G+; TestPoint_Keystone_5019_Miniature
TP7: B+; TestPoint_Keystone_5019_Miniature
TP9: GND; TestPoint_Pad_D2.0mm
TP10: 5V; TestPoint_Pad_D2.0mm
TP11: D; TestPoint_Pad_D2.0mm
U3: ESP32-S3-WROOM-1(N8R8); WIRELM-SMD_ESP32-S3-WROOM-1; LCSC Part C2913201

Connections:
+3.3V: C41.2, C42.1, MIC1.1 (VDD), R16.1, R25.1, R26.2, R27.1, U3.2 (3V3), U3.3 (EN); also elsewhere on the board
+5V: CN2.2, LED1.1 (VDD), TP10.1 (1_1); also elsewhere on the board
+20V: R21.1; also elsewhere on the board
/BOOT: R16.2, SW1.2, U3.27 (IO0)
/CH224A_SCL: U3.17 (IO9); also elsewhere on the board
/CH224A_SDA: U3.12 (IO8); also elsewhere on the board
/D+: U3.14 (IO20); also elsewhere on the board
/D-: U3.13 (IO19); also elsewhere on the board
/EN_B: U3.31 (IO38); also elsewhere on the board
/EN_G: U3.32 (IO39); also elsewhere on the board
/EN_R: U3.33 (IO40); also elsewhere on the board
/FAN_PWM: Q4.1 (G), R26.1, U3.6 (IO6)
/FAN_TACH: CN2.3, R25.2, U3.7 (IO7)
/LED_DIN: LED1.4 (DIN), U3.19 (IO11)
/MIC_CLK: MIC1.4 (CLK), U3.20 (IO12)
/MIC_DATA: MIC1.3 (DATA), U3.21 (IO13)
/NTC_ADC: C43.2, R27.2, TP1.1 (1_1), U3.18 (IO10)
/RX: CN1.1, U3.36 (RXD0)
/TX: CN1.3, U3.37 (TXD0)
/VIN_ADC: C40.2, R20.1, R21.2, U3.4 (IO4)
/driverB/VOUT: TP7.1 (1_1); also elsewhere on the board
/driverG/VOUT: TP5.1 (1_1); also elsewhere on the board
/driverR/VOUT: TP3.1 (1_1); also elsewhere on the board
GND: C40.1, C41.1, C42.2, C43.1, CN1.2, CN1.4, CN1.5, CN2.1, H1.1 (1_1), H2.1 (1_1), H3.1 (1_1), H4.1 (1_1), H5.1 (1_1), LED1.3 (VSS), MIC1.2 (GND), MIC1.5 (GND), MIC1.6 (L/R), Q4.2 (S), R20.2, SW1.1, TP2.1 (1_1), TP4.1 (1_1), TP6.1 (1_1), TP8.1 (1_1), TP9.1 (1_1), U3.1 (GND), U3.40 (GND), U3.41 (GND); also elsewhere on the board
unnamed: LED1.2 (DOUT), TP11.1 (1_1)
unnamed: CN2.4, Q4.3 (D)

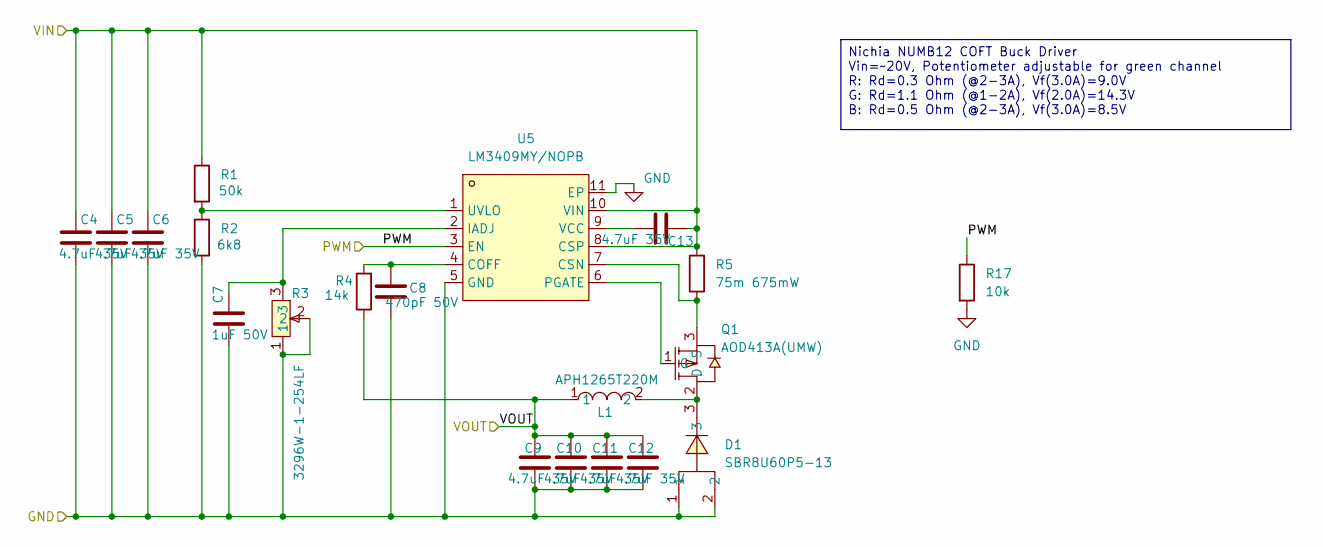
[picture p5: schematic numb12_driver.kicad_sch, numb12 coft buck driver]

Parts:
C4, C5, C6, C9, C10, C11, C12, C13: 4.7uF 35V; C_0603_1608Metric; LCSC Part C307467
C7: 1uF 50V; C_0603_1608Metric; LCSC Part C5199872
C8: 470pF 50V; C_0603_1608Metric; LCSC Part C16194503
D1: SBR8U60P5-13; POWERDI-5_L5.4-W4.0-LS6.5-RD-thermal; LCSC Part C154726
L1: APH1265T220M; IND-SMD_L13.5-W12.8_APH1265T; LCSC Part C5349635
Q1: AOD413A(UMW); TO-252-3_L6.6-W6.1-P4.57-LS9.9-BR-CW-thermal; LCSC Part C19100585
R1: 50k; R_0603_1608Metric; LCSC Part C861451
R2: 6k8; R_0603_1608Metric; LCSC Part C2907055
R3: 3296W-1-254LF; RES-ADJ-TH_3296W-clean; LCSC Part C83691
R4: 14k; R_0603_1608Metric; LCSC Part C723488
R5: 75m 675mW; R_1206_3216Metric; LCSC Part C2904225
R17: 10k; R_0603_1608Metric; LCSC Part C2906982
U5: LM3409MY/NOPB; HVSSOP-10_L3.0-W3.0-P0.50-LS4.9-BL-EP-thermal; LCSC Part C527401

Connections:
+20V: C4.1, C5.1, C6.1, C13.1, R1.1, R5.2, U5.8 (CSP), U5.10 (VIN); also elsewhere on the board
/EN_R: R17.1, U5.3 (EN); also elsewhere on the board
/driverR/VOUT: C9.1, C10.1, C11.1, C12.1, L1.1, R4.1; also elsewhere on the board
GND: C4.2, C5.2, C6.2, C7.2, C8.2, C9.2, C10.2, C11.2, C12.2, D1.1, D1.2, R2.2, R3.1, R3.2, R17.2, U5.5 (GND), U5.11 (EP); also elsewhere on the board
unnamed: D1.3, L1.2, Q1.2 (D)
unnamed: Q1.1 (G), U5.6 (PGATE)
unnamed: Q1.3 (S), R5.1, U5.7 (CSN)
unnamed: C8.1, R4.2, U5.4 (COFF)
unnamed: C7.1, R3.3, U5.2 (IADJ)
unnamed: R1.2, R2.1, U5.1 (UVLO)
unnamed: C13.2, U5.9 (VCC)

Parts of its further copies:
C14, C15, C16, C19, C20, C21, C22, C23, C24, C25, C26, C29, C30, C31, C32, C33: 4.7uF 35V; C_0603_1608Metric; LCSC Part C307467
C17, C27: 1uF 50V; C_0603_1608Metric; LCSC Part C5199872
C18, C28: 470pF 50V; C_0603_1608Metric; LCSC Part C16194503
D2, D3: SBR8U60P5-13; POWERDI-5_L5.4-W4.0-LS6.5-RD-thermal; LCSC Part C154726
L2, L3: APH1265T220M; IND-SMD_L13.5-W12.8_APH1265T; LCSC Part C5349635
Q2, Q3: AOD413A(UMW); TO-252-3_L6.6-W6.1-P4.57-LS9.9-BR-CW-thermal; LCSC Part C19100585
R6, R11: 50k; R_0603_1608Metric; LCSC Part C861451
R7, R12: 6k8; R_0603_1608Metric; LCSC Part C2907055
R8, R13: 3296W-1-254LF; RES-ADJ-TH_3296W-clean; LCSC Part C83691
R9, R14: 14k; R_0603_1608Metric; LCSC Part C723488
R10, R15: 75m 675mW; R_1206_3216Metric; LCSC Part C2904225
R18, R19: 10k; R_0603_1608Metric; LCSC Part C2906982
U6, U7: LM3409MY/NOPB; HVSSOP-10_L3.0-W3.0-P0.50-LS4.9-BL-EP-thermal; LCSC Part C527401

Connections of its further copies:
+20V: C14.1, C15.1, C16.1, C23.1, C24.1, C25.1, C26.1, C33.1, R6.1, R10.2, R11.1, R15.2, U6.8 (CSP), U6.10 (VIN), U7.8 (CSP), U7.10 (VIN); also elsewhere on the board
/EN_B: R19.1, U7.3 (EN); also elsewhere on the board
/EN_G: R18.1, U6.3 (EN); also elsewhere on the board
/driverB/VOUT: C29.1, C30.1, C31.1, C32.1, L3.1, R14.1; also elsewhere on the board
/driverG/VOUT: C19.1, C20.1, C21.1, C22.1, L2.1, R9.1; also elsewhere on the board
GND: C14.2, C15.2, C16.2, C17.2, C18.2, C19.2, C20.2, C21.2, C22.2, C24.2, C25.2, C26.2, C27.2, C28.2, C29.2, C30.2, C31.2, C32.2, D2.1, D2.2, D3.1, D3.2, R7.2, R8.1, R8.2, R12.2, R13.1, R13.2, R18.2, R19.2, U6.5 (GND), U6.11 (EP), U7.5 (GND), U7.11 (EP); also elsewhere on the board
unnamed: D2.3, L2.2, Q2.2 (D)
unnamed: Q2.1 (G), U6.6 (PGATE)
unnamed: Q2.3 (S), R10.1, U6.7 (CSN)
unnamed: D3.3, L3.2, Q3.2 (D)
unnamed: Q3.1 (G), U7.6 (PGATE)
unnamed: Q3.3 (S), R15.1, U7.7 (CSN)
unnamed: C18.1, R9.2, U6.4 (COFF)
unnamed: C17.1, R8.3, U6.2 (IADJ)
unnamed: R6.2, R7.1, U6.1 (UVLO)
unnamed: C23.2, U6.9 (VCC)
unnamed: C28.1, R14.2, U7.4 (COFF)
unnamed: C27.1, R13.3, U7.2 (IADJ)
unnamed: R11.2, R12.1, U7.1 (UVLO)
unnamed: C33.2, U7.9 (VCC)

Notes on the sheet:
Nichia NUMB12 COFT Buck Driver Vin=~20V, Potentiometer adjustable for green channel R: Rd=0.3 Ohm (@2-3A), Vf(3.0A)=9.0V G: Rd=1.1 Ohm (@1-2A), Vf(2.0A)=14.3V B: Rd=0.5 Ohm (@2-3A), Vf(3.0A)=8.5V

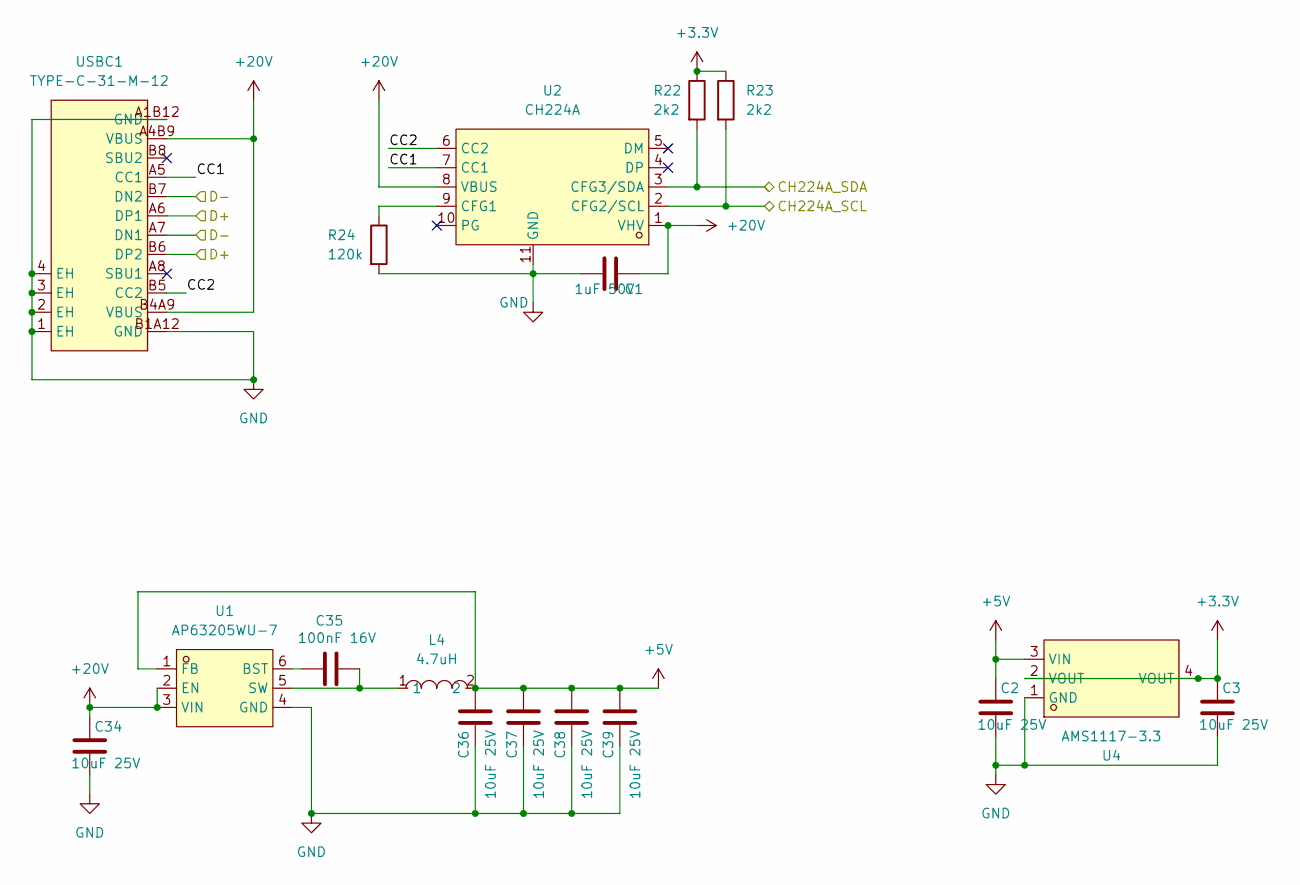
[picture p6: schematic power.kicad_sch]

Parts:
C1: 1uF 50V; C_0603_1608Metric; LCSC Part C5199872
C2, C3, C34, C36, C37, C38, C39: 10uF 25V; C_0603_1608Metric; LCSC Part C96446
C35: 100nF 16V; C_0603_1608Metric; LCSC Part C346192
L4: 4.7uH; IND-SMD_L4.4-W4.2; MPN APH0420T4R7M; LCSC Part C5349668
R22, R23: 2k2; R_0603_1608Metric; LCSC Part C2907005
R24: 120k; R_0603_1608Metric; LCSC Part C2907095
U1: AP63205WU-7; TSOT-23-6_L2.9-W1.6-P0.95-LS2.8-BL; MPN AP63205WU-7; LCSC Part C2071056
U2: CH224A; ESSOP-10_L4.9-W3.9-P1.0-LS6.0-TL-EP; LCSC Part C42459160
U4: AMS1117-3.3; SOT-223-3_L6.5-W3.4-P2.30-LS7.0-BR; LCSC Part C6186
USBC1: TYPE-C-31-M-12; USB-C_SMD-TYPE-C-31-M-12_1; LCSC Part C165948

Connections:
+3.3V: C3.1, R22.1, R23.1, U4.2 (VOUT), U4.4 (VOUT); also elsewhere on the board
+5V: C2.1, C36.1, C37.1, C38.1, C39.1, L4.2, U1.1 (FB), U4.3 (VIN); also elsewhere on the board
+20V: C1.1, C34.1, U1.2 (EN), U1.3 (VIN), U2.1 (VHV), U2.8 (VBUS), USBC1.A4B9 (VBUS), USBC1.B4A9 (VBUS); also elsewhere on the board
/CH224A_SCL: R23.2, U2.2 (CFG2/SCL); also elsewhere on the board
/CH224A_SDA: R22.2, U2.3 (CFG3/SDA); also elsewhere on the board
/D+: USBC1.A6 (DP1), USBC1.B6 (DP2); also elsewhere on the board
/D-: USBC1.A7 (DN1), USBC1.B7 (DN2); also elsewhere on the board
/power/CC1: U2.7 (CC1), USBC1.A5 (CC1)
/power/CC2: U2.6 (CC2), USBC1.B5 (CC2)
GND: C1.2, C2.2, C3.2, C34.2, C36.2, C37.2, C38.2, C39.2, R24.2, U1.4 (GND), U2.11 (GND), U4.1 (GND), USBC1.1 (EH), USBC1.2 (EH), USBC1.3 (EH), USBC1.4 (EH), USBC1.A1B12 (GND), USBC1.B1A12 (GND); also elsewhere on the board
unnamed: C35.1, U1.6 (BST)
unnamed: C35.2, L4.1, U1.5 (SW)
unnamed: R24.1, U2.9 (CFG1)

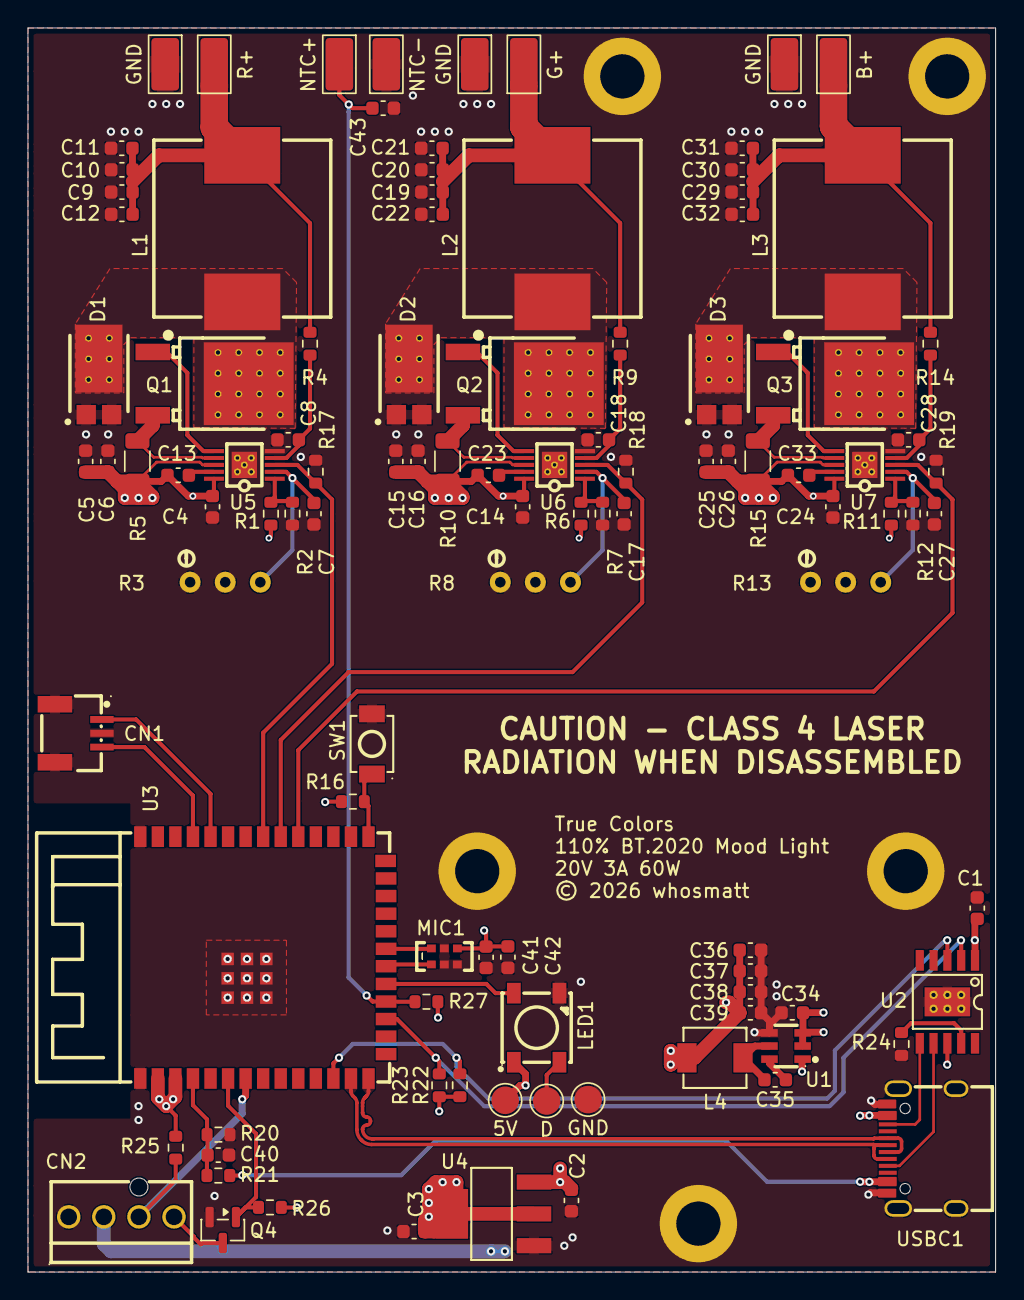
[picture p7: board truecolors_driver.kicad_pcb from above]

Board: 4 copper layers, 70.0 x 90.0 mm, 110 parts (0 on the bottom side), 52 nets.

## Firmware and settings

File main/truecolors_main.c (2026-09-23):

// truecolors_main.c STUB
#include "esp_log.h"
#include "esp_ota_ops.h"
#include "nvs_flash.h"

#include "app_events.h"
#include "appstate.h"
#include "storage.h"
#include "laser.h"
#include "effects.h"
#include "audio.h"
#include "beattrack.h"
#include "beatnn.h"
#include "sysmgr.h"
#include "wifi_mgr.h"
#include "server.h"

static const char *TAG = "main";

void app_main(void)
{
    ESP_LOGI(TAG, "truecolors boot");

    // 1. NVS init + scene staging
    esp_err_t nerr = nvs_flash_init();
    if (nerr == ESP_ERR_NVS_NO_FREE_PAGES || nerr == ESP_ERR_NVS_NEW_VERSION_FOUND) {
        ESP_ERROR_CHECK(nvs_flash_erase());
        ESP_ERROR_CHECK(nvs_flash_init());
    }
    ESP_ERROR_CHECK(storage_init());

    // 2. GPIO defaults: lasers held off by EN pulldowns, fan off via R26

    // 3. App event bus + state mutex + state model.
    ESP_ERROR_CHECK(app_bus_init());
    ESP_ERROR_CHECK(appstate_init());

    // 4. Laser (MCPWM, widths 0, generators LOW), effects registry, audio (I2S).
    ESP_ERROR_CHECK(laser_init());
    laser_set_pwm_hz(storage_load_pwm_hz());
    ESP_ERROR_CHECK(effects_init());
    effects_set_epilepsy_safe(storage_load_epilepsy_safe());
    esp_err_t merr = beatnn_init();
    if (merr != ESP_OK) {
        ESP_LOGE(TAG, "beat model disabled: %s", esp_err_to_name(merr));
    }
    ESP_ERROR_CHECK(audio_init());
    ESP_ERROR_CHECK(beattrack_start());

    // 5. System manager + status LED + safety gate.
    ESP_ERROR_CHECK(sysmgr_init());

    // 6. Wi-Fi (STA -> AP fallback) + mDNS/hostname.
    ESP_ERROR_CHECK(wifi_start());

    // 7. HTTP server (SPA + OTA + /ws) + bus subscribers.
    ESP_ERROR_CHECK(server_start());

    // 8. Prime the scene from persisted state (STORAGE_RESTORE patch).
    ESP_ERROR_CHECK(storage_restore_scene());

    // 9. Start periodic tasks (render / monitor / audio).
    ESP_ERROR_CHECK(effects_start_render());
    ESP_ERROR_CHECK(sysmgr_start());

    // Basic OTA safety, we don't check more than basic bringup for now
    esp_err_t verr = esp_ota_mark_app_valid_cancel_rollback();
    if (verr != ESP_OK) {
        ESP_LOGW(TAG, "mark app valid failed: %s", esp_err_to_name(verr));
    }

    ESP_LOGI(TAG, "boot success");
}

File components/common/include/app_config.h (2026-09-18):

// app_config.h

#pragma once

// ---------------------------------------------------------------------------
// Laser PWM / drive (MCPWM)
// ---------------------------------------------------------------------------
#define TC_PWM_HZ            120        // default RGB cycle frequency, quiet; runtime-adjustable
#define MCPWM_CLK_HZ         5000000    // 5 MHz group clock -> 0.2 us/tick; the
                                        // 16-bit period register then reaches
                                        // down to ~80 Hz (120 Hz = 41666 ticks)
#define GAP_US               0          // guard gap: settled at 0 (not an H-bridge)
#define MIN_ON_US            8          // LM3409 settle floor, 5-10 us (tune on scope)
#define GAMMA                2.2f       // float gamma exponent (calibratable)

// Derived tick budget (period in MCPWM ticks).
#define TC_PERIOD_TICKS      (MCPWM_CLK_HZ / TC_PWM_HZ)            // 120 Hz -> 41666
#define GAP_TICKS            ((GAP_US * (MCPWM_CLK_HZ / 1000000))) // 0
#define MIN_ON_TICKS         (MIN_ON_US * (MCPWM_CLK_HZ / 1000000))

// ---------------------------------------------------------------------------
// Thermal / fan
// ---------------------------------------------------------------------------
#define FAN_TARGET_C         45.0f      // PID setpoint (laser-module NTC)
#define FAN_PWM_HZ           25000      // 25 kHz, inaudible
#define FAN_PWM_RES_BITS     10         // LEDC resolution
#define FAN_PULSES_PER_REV   2          // confirmed
#define FAN_KICK_DUTY        0.30f      // spin-up burst while tach reads 0 rpm
// Measured ramp 2026-07-07: ~84 rpm floor below the knee, rpm = 1875*duty - 250
// above it, linear to 1621 rpm at 100%, no hysteresis.
#define FAN_KNEE_DUTY        0.19f      // PID demand maps onto [knee, 1]
#define STALL_WARN_S         1.0f       // tach silent this long -> warning (kick is attempting a start)
#define STALL_FAIL_S         15.0f      // tach silent this long -> start failed, latched error
// Tuned from logged limit cycle 2026-07-06, rescaled by 1/(1-knee) for the
// knee remap so loop dynamics around equilibrium stay the same.
#define FAN_KP               0.12f
#define FAN_KI               0.0012f

// ---------------------------------------------------------------------------
// Safety thresholds
// ---------------------------------------------------------------------------
#define T_LIMIT_C            50.0f      // overtemp latching fault threshold
#define VIN_NOMINAL_V        20.0f
#define VIN_WARN_V           17.0f      // below this -> "vin_low" warning (no shutdown)
// Current draw vs supply, measured 2026-07-07: 2.4 A @ 12 V,
// 2.1 A @ 15 V, 1.55 A @ 20 V (beautifully linear).
#define LASER_A_INTERCEPT    3.68f
#define LASER_A_PER_VOLT     -0.106f
#define LASER_A_MARGIN       0.2f
#define NTC_V_OPEN           3.25f      // above this the NTC reads open
#define NTC_V_SHORT          0.05f      // below this the NTC reads shorted
#define BTN_DEBOUNCE_MS      60

// ---------------------------------------------------------------------------
// Sensing / ADC
// ---------------------------------------------------------------------------
#define ADC_VREF_V           3.3f
#define VIN_DIVIDER_SCALE    7.8f       // (68k + 10k) / 10k
#define ADC_OVERSAMPLE_N     16         // samples averaged per read

// NTC (laser module): 10k @ 25 C, B = 3950.
#define NTC_R_NOMINAL        10000.0f
#define NTC_R_SERIES         10000.0f   // 10k pull-up to 3.3 V
#define NTC_B_VALUE          3950.0f
#define NTC_T0_K             298.15f    // 25 C in kelvin

// ---------------------------------------------------------------------------
// CH224A USB-PD sink (I2C, single-byte transactions only)
// ---------------------------------------------------------------------------
#define CH224A_ADDR_A        0x22       // probe both at init (confirm on hardware)
#define CH224A_ADDR_B        0x23
#define CH224A_I2C_HZ        400000
#define CH224A_REG_STATUS    0x09       // RO: bit3 = PD handshake good
#define CH224A_REG_CURRENT   0x50       // RO: max current, 50 mA/count
#define CH224A_REG_VOLTAGE   0x0A       // WO: gear select (4 = 20 V)
#define CH224A_STATUS_PD_BIT (1 << 3)
#define CH224A_CURRENT_MA_PER_COUNT 50

// ---------------------------------------------------------------------------
// Timing / rates
// ---------------------------------------------------------------------------
#define RENDER_HZ            90         // laser_render task target (60-120 Hz)
#define MONITOR_HZ           10         // sysmgr internal poll rate (5-10 Hz)
#define METRICS_HZ           1          // metrics/telemetry publish rate
#define STATUS_LED_HZ        50         // animation engine tick (smooth fades)
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

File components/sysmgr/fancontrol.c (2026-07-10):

// fancontrol.c
#include "fancontrol.h"
#include "board_pins.h"
#include "app_config.h"

#include "driver/ledc.h"
#include "esp_log.h"

static const char *TAG = "fancontrol";

#define FAN_DUTY_MAX ((1 << FAN_PWM_RES_BITS) - 1)

static float s_integ;

esp_err_t fancontrol_init(void)
{
    ledc_timer_config_t timer_cfg = {
        .speed_mode = LEDC_FAN_MODE,
        .timer_num = LEDC_FAN_TIMER,
        .duty_resolution = FAN_PWM_RES_BITS,
        .freq_hz = FAN_PWM_HZ,
        .clk_cfg = LEDC_AUTO_CLK,
    };
    ESP_ERROR_CHECK(ledc_timer_config(&timer_cfg));

    ledc_channel_config_t ch_cfg = {
        .gpio_num = PIN_FAN_PWM,
        .speed_mode = LEDC_FAN_MODE,
        .channel = LEDC_FAN_CHANNEL,
        .timer_sel = LEDC_FAN_TIMER,
        .duty = 0,
        .hpoint = 0,
        .flags.output_invert = 1,
    };
    ESP_ERROR_CHECK(ledc_channel_config(&ch_cfg));

    ESP_LOGI(TAG, "fan ready, %d Hz", FAN_PWM_HZ);
    return ESP_OK;
}

float fancontrol_update(float temp_c, int fan_rpm, float dt)
{
    float err = temp_c - FAN_TARGET_C;
    float unclamped = FAN_KP * err + FAN_KI * (s_integ + err * dt);

    float u = unclamped;
    if (u < 0.0f) u = 0.0f;
    if (u > 1.0f) u = 1.0f;

    // Integrate only when not saturated.
    if (u == unclamped) {
        s_integ += err * dt;
    }

    // Linearize fan response
    float duty = u > 0.0f ? FAN_KNEE_DUTY + u * (1.0f - FAN_KNEE_DUTY) : 0.0f;

    // Fan may sometimes start stalled, kick it
    if (fan_rpm == 0 && duty < FAN_KICK_DUTY) {
        duty = FAN_KICK_DUTY;
    }

    // If the fan stays at 0 rpm for STALL_FAIL_S, it latches a persistent error 

    uint32_t reg = (uint32_t)(duty * FAN_DUTY_MAX);
    ledc_set_duty(LEDC_FAN_MODE, LEDC_FAN_CHANNEL, reg);
    ledc_update_duty(LEDC_FAN_MODE, LEDC_FAN_CHANNEL);

    return duty;
}

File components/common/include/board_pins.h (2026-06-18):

// board_pins.h

#pragma once

#include "driver/gpio.h"

// ---------------------------------------------------------------------------
// GPIO map (ESP32-S3-WROOM-1 N8R8)
// ---------------------------------------------------------------------------
// Laser enables, active-high to the LM3409 EN/PWM input.
// Each net has a 10k pulldown so lasers stay off while the GPIO is Hi-Z.
#define PIN_EN_R        GPIO_NUM_40   // MCPWM operator 0 -> driverR
#define PIN_EN_G        GPIO_NUM_39   // MCPWM operator 1 -> driverG
#define PIN_EN_B        GPIO_NUM_38   // MCPWM operator 2 -> driverB

// Fan (5 V 4-wire PC fan via low-side BSS138).
#define PIN_FAN_PWM     GPIO_NUM_6    // LEDC, 25 kHz, output_invert=1
#define PIN_FAN_TACH    GPIO_NUM_7    // PCNT, open-collector, 10k pull-up to 3.3 V

// CH224A USB-PD sink (I2C master).
#define PIN_I2C_SDA     GPIO_NUM_8    // 2.2k pull-up to 3.3 V
#define PIN_I2C_SCL     GPIO_NUM_9    // 2.2k pull-up to 3.3 V

// Analog sense on ADC1. ADC2 is unusable while Wi-Fi is active.
#define PIN_VIN_ADC     GPIO_NUM_4    // ADC1_CH3, 20 V rail via 68k/10k divider
#define PIN_NTC_ADC     GPIO_NUM_10   // ADC1_CH9, laser-module NTC via 10k/NTC divider

// PDM MEMS microphone (MSM261DGT003).
#define PIN_MIC_CLK     GPIO_NUM_12   // I2S PDM CLK
#define PIN_MIC_DATA    GPIO_NUM_13   // I2S PDM DATA (RX)

// WS2812B-B status LED.
#define PIN_LED_DATA    GPIO_NUM_11   // RMT TX (led_strip)

// User button / boot strap (SW1 + 10k pull-up to 3.3 V).
// Boot strap at reset; free to read as a button once running.
#define PIN_BTN         GPIO_NUM_0

// ---------------------------------------------------------------------------
// Peripheral-unit allocation
// ---------------------------------------------------------------------------
// MCPWM: one group, one timer, three operators.
#define MCPWM_GROUP_ID      0
#define MCPWM_TIMER_ID      0
#define MCPWM_OPER_R        0
#define MCPWM_OPER_G        1
#define MCPWM_OPER_B        2

// LEDC fan PWM.
#define LEDC_FAN_MODE       LEDC_LOW_SPEED_MODE
#define LEDC_FAN_TIMER      LEDC_TIMER_0
#define LEDC_FAN_CHANNEL    LEDC_CHANNEL_0

// PCNT fan tach.
#define PCNT_FAN_UNIT_ID    0

// I2C CH224A bus.
#define I2C_PORT_CH224A     0

// I2S PDM RX microphone.
#define I2S_PORT_MIC        0

// ADC sense channels on ADC1.
#define ADC_UNIT_SENSE      ADC_UNIT_1
#define ADC_CH_VIN          ADC_CHANNEL_3   // GPIO4
#define ADC_CH_NTC          ADC_CHANNEL_9   // GPIO10

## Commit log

2026-06-13 add pcb
    [numb12_driver.kicad_sch, truecolors_driver.kicad_pcb, truecolors_driver.kicad_sch]
2026-06-13 update pcb
    [numb12_driver.kicad_sch, truecolors_driver.kicad_pcb, truecolors_driver.kicad_sch]
2026-06-13 R26 pullup instead of pulldown for fan-off boot
    [truecolors_driver.kicad_pcb, truecolors_driver.kicad_sch]
2026-06-14 add mic, add ntc, fix all drc errors
    [truecolors_driver.kicad_pcb, truecolors_driver.kicad_sch]
2026-06-14 refactor schematic
    [power.kicad_sch, truecolors_driver.kicad_pcb, truecolors_driver.kicad_sch]
2026-06-14 add mounting holes, labels
    [power.kicad_sch, truecolors_driver.kicad_pcb, truecolors_driver.kicad_sch]
2026-06-14 finalize bom
    [numb12_driver.kicad_sch, power.kicad_sch, truecolors_driver.csv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]
2026-06-14 fix missing labels
    [truecolors_driver.kicad_pcb]
2026-06-14 add status led
    [truecolors_driver.kicad_pcb, truecolors_driver.kicad_sch]
2026-06-14 update bom
    [truecolors_driver.csv]
2026-06-16 pin container
2026-06-16 fix line endings :)
    [numb12_driver.kicad_sch, power.kicad_sch, truecolors_driver.kicad_pcb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]
2026-06-17 fix typo
    [truecolors_driver.kicad_pcb]
2026-06-18 init idf project, init deps, init components
    [partitions.csv]
2026-06-18 implement core laser driver
2026-06-18 implement sysmgr, safety state machine, fan control
2026-06-20 add mechanical files
    [full assy.f3z, full assy.step]
2026-06-24 drop udev and just mount dev instead, drop privileged and add cgroup rules
2026-06-24 fix esp32 mcu temp sensor readout
    [sysmgr.c]
2026-06-24 fix: ws events not reaching other clients
    [ws.c]
2026-06-28 pin esp-idf to 6.0.1, set WDT explicitly since this idf version lowers the default
2026-07-06 allow full current if no PD source found
2026-07-06 fix: stretch could cause channels to latch up under certain conditions
    [laser.c]
2026-07-06 add optional keepalive to effects to prevent driver from going into low-power shutdown
    [laser.c]
2026-07-06 subtle solid status led while running
2026-07-06 update fan controller: tune pid loop and adjust rpm readout precision
2026-07-06 don't store power state, default to off
2026-07-06 dim and calm idle status led animation
2026-07-07 fancontrol: linearize fan response
2026-07-07 ws: track patch origin to prevent patches looping back to sender
    [ws.c]
2026-07-07 safety: turn undercurrent into warning only, characterize and model current draw
2026-07-07 safety: drop temperature limit to 50C
2026-07-10 fancontrol: improve stall detection and add stall recovery
    [app_config.h, fancontrol.c, sysmgr.c]
2026-07-19 add beatgrid visualizer with socket for debugging, make beat metronome only (previously kick pattern), jitter reduction in kick detection
    [ws.c]
2026-09-18 relax fan stall fault timer
    [app_config.h]
2026-09-18 update board after coil whine mitigations
    [numb12_driver.kicad_sch, truecolors_driver.csv]
2026-09-19 pin http and tcpip to core0 so core1 audio headroom stays consistent
2026-09-20 add compile time flags for frontend filters
2026-09-23 wire up beatnn and add beatnn ws debug
2026-09-29 deploy v4 dual-stage model
2026-10-23 automatically restore power state if PD is good
2026-10-23 add button confirmation mechanism

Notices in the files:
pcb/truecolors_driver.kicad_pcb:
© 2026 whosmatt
